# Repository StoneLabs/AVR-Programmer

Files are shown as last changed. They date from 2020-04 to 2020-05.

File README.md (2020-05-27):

  

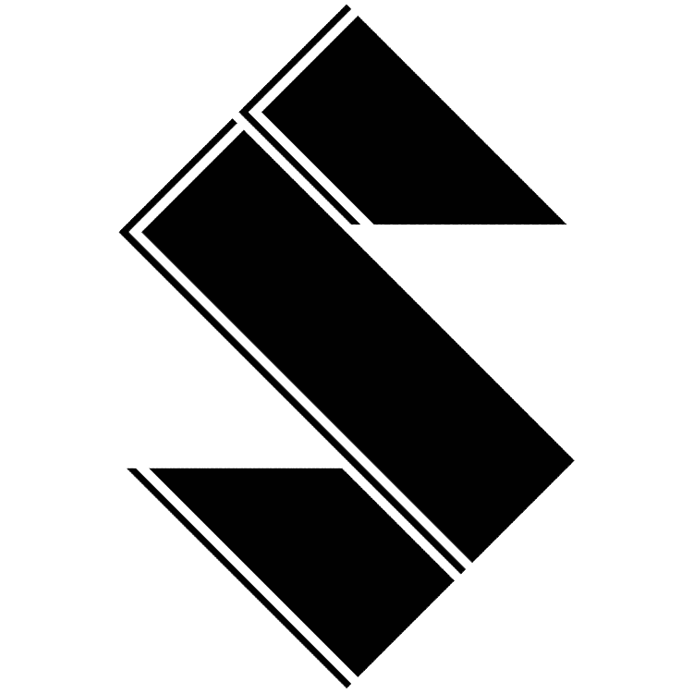
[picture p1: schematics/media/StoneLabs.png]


# Stone Labs. AVR-Programmer
Schematics and firmware for a portable In-Service-Programmer. It is designed to be powered by a 9V battery and uses an OLED Display module for user interaction. INTEL HEX Files can be flashed to target chips via an ISP-6 port directly from an SD-Card.

# PCB

The Programmer is designed to sit on a portable ~9x11cm PCB. Eagle files for the PCB can be found in the `schematics` folder. Target chips can be programmed with the 6-pin Header located at the top of the PCB. There is also an 8Mhz clock pin available (TCLK) in case the target needs an external clock and none is available. BOM for the programmer can be found in `schematics/bom-grouped.csv`. All parts are available from DIGI-KEY. The price per assembled PCB should be around 10-30 bucks depending on the order quantity.

Aside from the programmer, there is target PCB design under `schematics-target`. The target can hold an ATmega328P like chip that can be programmed by connecting the target boards ISP Header to the programmer ISP-Port.

[Picture of PCB revision 1 (Release_V-1.0)](/pcb_v-1.0.png)

| PCB | Version | Status |
| - | - | - |
| Main PCB | Hardware_V-1.0 | Pull-Ups R1, R2 are connected incorrectly (to GND instead of +5V)! Assembled and tested. Works without R1, R2. |
| Main PCB | Hardware_V-1.1 | Fixed only R1, R2 and should work better than V-1.0. Untested! |
| Main PCB | Hardware_V-1.1+ | No functional hardware change. |
| Target PCB | Hardware_V-1.2 | Assembled and tested. Fully functional. |

# INTEL HEX

All `.hex` or `.HEX` files in the root folder of the SD-Card can be flashed to the target using the Programmer. The algorithm used for flashing the program to the target is very robust against weirdly formed hex files (e.g. line swaps, different lengths of lines in the same file, etc.). HEX record types 00, 01, and 02 are fully supported. Type 03 entries will be ignored with a warning sent to the programmers Serial output. Type 04 and 05 are not supported and HEX files containing those record types can't be flashed. (This shouldn't be an issue for AVR chips).

The programmer will also scan all possible bootloader positions for the current target and automatically set the fuse containing the bootloader position bits as needed.

# Supported chips

#32CD32 Supported and tested  
#FFA500 Supported not tested  
#f03c15 Not yet supported  

||Chip||Chip|
| - | - | - | - |
|  #FFA500 | ATmega1280 |  #f03c15 | ATmega329A |
|  #FFA500 | ATmega1281 |  #f03c15 | ATmega329PA |
|  #FFA500 | ATmega1284P |  #f03c15 | ATmega329P |
|  #FFA500 | ATmega1284 |  #f03c15 | ATmega329 |
|  #f03c15 | ATmega128A |  #f03c15 | ATmega32A |
|  #f03c15 | ATmega128RFA1 |  #f03c15 | ATmega32C1 |
|  #f03c15 | ATmega128 |  #f03c15 | ATmega32HVB |
|  #f03c15 | ATmega162 |  #f03c15 | ATmega32M1 |
|  #f03c15 | ATmega164A |  #FFA500 | ATmega32U2 |
|  #f03c15 | ATmega164PA |  #FFA500 | ATmega32U4 |
|  #FFA500 | ATmega164P |  #f03c15 | ATmega32 |
|  #f03c15 | ATmega165A |  #f03c15 | ATmega48A |
|  #f03c15 | ATmega165PA |  #FFA500 | ATmega48PA |
|  #f03c15 | ATmega165P |  #f03c15 | ATmega48P |
|  #f03c15 | ATmega168A |  #f03c15 | ATmega48 |
|  #FFA500 | ATmega168PA |  #f03c15 | ATmega640 |
|  #f03c15 | ATmega168P |  #f03c15 | ATmega644A |
|  #FFA500 | ATmega168V |  #f03c15 | ATmega644PA |
|  #f03c15 | ATmega168 |  #FFA500 | ATmega644P |
|  #f03c15 | ATmega169A |  #f03c15 | ATmega644 |
|  #f03c15 | ATmega169PA |  #f03c15 | ATmega6450A |
|  #f03c15 | ATmega169P |  #f03c15 | ATmega6450P |
|  #f03c15 | ATmega16A |  #f03c15 | ATmega6450 |
|  #f03c15 | ATmega16HVB |  #f03c15 | ATmega645A |
|  #f03c15 | ATmega16M1 |  #f03c15 | ATmega645P |
|  #FFA500 | ATmega16U2 |  #f03c15 | ATmega645 |
|  #FFA500 | ATmega16U4 |  #f03c15 | ATmega6490A |
|  #f03c15 | ATmega16 |  #f03c15 | ATmega6490P |
|  #FFA500 | ATmega2560 |  #f03c15 | ATmega6490 |
|  #FFA500 | ATmega2561 |  #f03c15 | ATmega649A |
|  #f03c15 | ATmega324A |  #f03c15 | ATmega649P |
|  #f03c15 | ATmega324PA |  #f03c15 | ATmega649 |
|  #FFA500 | ATmega324P |  #f03c15 | ATmega64A |
|  #f03c15 | ATmega3250A |  #f03c15 | ATmega64C1 |
|  #f03c15 | ATmega3250PA  |  #f03c15 | ATmega64M1 |
|  #f03c15 | ATmega3250P |  #f03c15 | ATmega64 |
|  #f03c15 | ATmega3250 |  #f03c15 | ATmega8515 |
|  #f03c15 | ATmega325A |  #f03c15 | ATmega8535 |
|  #f03c15 | ATmega325PA |  #f03c15 | ATmega88A |
|  #f03c15 | ATmega325P |  #FFA500 | ATmega88PA |
|  #f03c15 | ATmega325 |  #f03c15 | ATmega88P |
|  #32CD32 | ATmega328P |  #f03c15 | ATmega88 |
|  #FFA500 | ATmega328PB |  #f03c15 | ATmega8A |
|  #FFA500 | ATmega328 |  #FFA500 | ATmega8U2 |
|  #f03c15 | ATmega3290A |  #f03c15 | ATmega8 |
|  #f03c15 | ATmega3290PA  |  #FFA500 | At90USB82 |
|  #f03c15 | ATmega3290P |  #FFA500 | At90USB162 |
|  #f03c15 | ATmega3290 | | |
| | | | |
|  #FFA500 | ATtiny24 |  #FFA500 | ATtiny25 |
|  #FFA500 | ATtiny44 |  #FFA500 | ATtiny45 |
|  #FFA500 | ATtiny84 |  #FFA500 | ATtiny85 |

# License

This is free and unencumbered software released into the public domain.

Anyone is free to copy, modify, publish, use, compile, sell, or
distribute this software, either in source code form or as a compiled
binary, for any purpose, commercial or non-commercial, and by any
means.

In jurisdictions that recognize copyright laws, the author or authors
of this software dedicate any and all copyright interest in the
software to the public domain. We make this dedication for the benefit
of the public at large and to the detriment of our heirs and
successors. We intend this dedication to be an overt act of
relinquishment in perpetuity of all present and future rights to this
software under copyright law.

THE SOFTWARE IS PROVIDED "AS IS", WITHOUT WARRANTY OF ANY KIND,
EXPRESS OR IMPLIED, INCLUDING BUT NOT LIMITED TO THE WARRANTIES OF
MERCHANTABILITY, FITNESS FOR A PARTICULAR PURPOSE AND NONINFRINGEMENT.
IN NO EVENT SHALL THE AUTHORS BE LIABLE FOR ANY CLAIM, DAMAGES OR
OTHER LIABILITY, WHETHER IN AN ACTION OF CONTRACT, TORT OR OTHERWISE,
ARISING FROM, OUT OF OR IN CONNECTION WITH THE SOFTWARE OR THE USE OR
OTHER DEALINGS IN THE SOFTWARE.

For more information, please refer to <http://unlicense.org/>

### That being said, I'd really like to hear from you if you plan on using this project somewhere. And I for sure wouldn't mind some part if you use it commercially ;) (e.g. selling it etc.)

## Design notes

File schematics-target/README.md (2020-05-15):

# Schematics

Eagle files for a simple target board holding an ATmega328P like chip in PDIP packaging. It can be used to easily hook up target chips.

The Graphics on the pcb can be found in media/.

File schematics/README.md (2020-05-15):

# Schematics

Eagle files for the programmer board as well as a diagram for arduino based testing (arduino_wiring.sch).

Parts.lbr contains the OLED screen used. (see also oled.jpg)

The Graphics on the pcb can be found in media/.

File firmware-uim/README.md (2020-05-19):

# UIM: User Interface Module

This is the firmware for the lower (on the pcb) chip handling the OLED screen and user input.

Actions are send to the programmer chip via I2C.

# Flowchart of user interaction

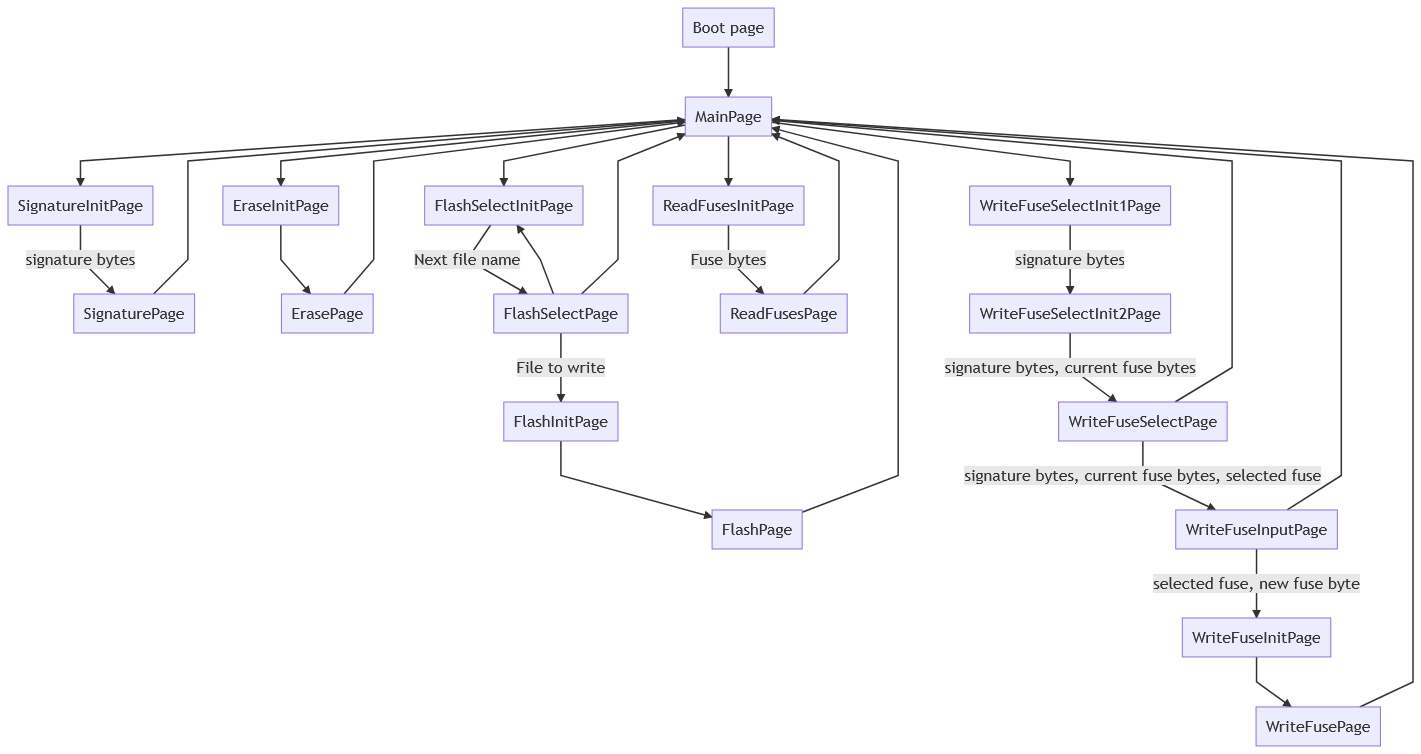
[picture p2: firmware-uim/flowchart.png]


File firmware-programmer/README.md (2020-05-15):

# Programmer

This is the firmware for the upper (on the pcb) chip handling the SPI programming of the target.

Actions are received by the UIM chip via I2C.

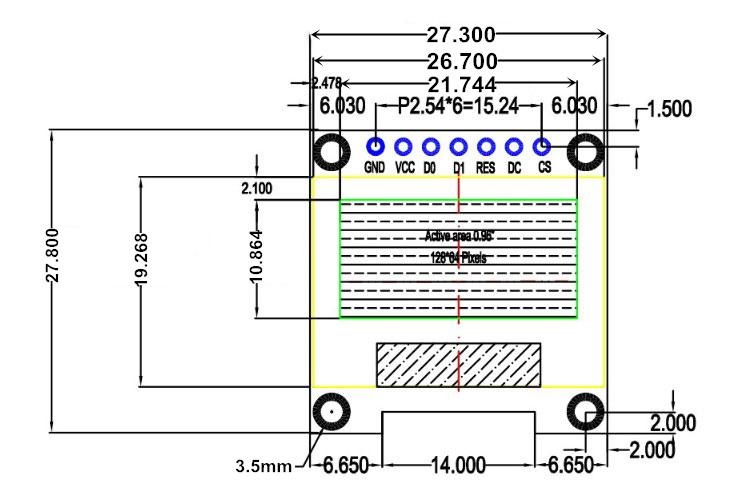
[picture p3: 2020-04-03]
schematics/oled.jpg

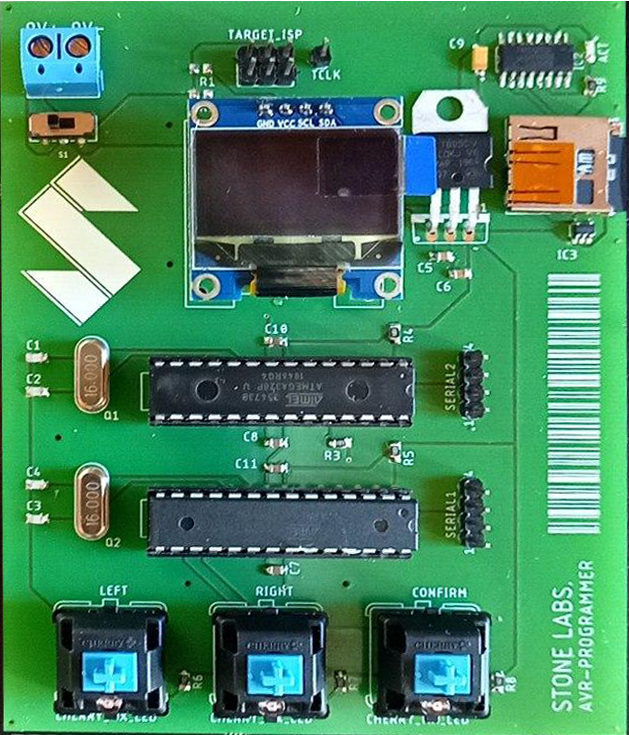
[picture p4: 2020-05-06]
pcb_v-1.0.png

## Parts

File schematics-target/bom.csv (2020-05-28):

Part | Value | Device | Package | Description
C1 | 22pF | C-EUC0805 | C0805 | CAPACITOR, European symbol
C2 | 22pF | C-EUC0805 | C0805 | CAPACITOR, European symbol
C3 | 100nF | C-EUC0805 | C0805 | CAPACITOR, European symbol
C4 | 100nF | C-EUC0805 | C0805 | CAPACITOR, European symbol
ISP | AVR-ISP-6 | AVR-ISP-6 | AVR-ISP-6 | AVR ISP-6 Serial Programming Header
Q1 | 16Mhz | XTAL/S | QS | CRYSTAL
R1 | 10k | R-EU_R0805 | R0805 | RESISTOR, European symbol
TARGET_ATMEGA328P | ATMEGA48/88/168-PU | ATMEGA48/88/168-PU | DIL28-3

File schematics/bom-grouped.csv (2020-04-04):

count Device | Device | Package | Value | Status | Digikey
5 | C-EUC0805 | C0805 | 100nF | ORDERED | ‎C0805C104Z5VACTU‎
5 | R-EU_R0805 | R0805 | 10k | ORDERED | RC0805JR-0710KL‎
4 | C-EUC0805 | C0805 | 22pF | ORDERED | ‎C0805C220J5GACTU‎
3 | CHERRY_MX_LED | CHERRY_MX_LED | CHERRY_MX_LED | ORDERED | MX1A-E1NN‎
3 | R-EU_R0805 | R0805 | 1k | ORDERED | RC0805JR-071KL‎
2 | ATMEGA48/88/168-PU | DIL28-3 | ATMEGA48/88/168-PU | Stock | Stock
2 | MA04-1 | MA04-1 |  | Stock | Stock
2 | XTAL/S | QS | 16Mhz | Stock | Stock
1 | 128X64-I2C-OLED | 128X64-I2C-OLED | 128X64-I2C-OLED | Stock | Stock
1 | 4050D | SO16 | 4050D | ORDERED | 74HC4050D,653‎
1 | 452404020202 | 452404020202 |  | ORDERED | 45 2404020202
1 | 7805TV | TO220V | 7805TV | Stock | Stock
1 | AVR-ISP-6 | AVR-ISP-6 | AVR-ISP-6 | Stock | Stock
1 | C-EUC0805 | C0805 | 330nF | ORDERED | ‎885012207019‎
1 | CPOL-USA/3216-18R | A/3216-18R | 10uF | ORDERED | TAJA106K006SNJ‎
1 | LEDCHIP-LED0805 | CHIP-LED0805 | RED | ORDERED | LTST-S220KGKT‎
1 | LP298XS | SOT23-5L | LP298XS | ORDERED | LP2980AIM5-3.0/NOPB‎
1 | MICROSD | MICROSD | MICROSD | ORDERED | 693071010811‎
1 | PINHD-1X1 | 1X01 |  | Stock | Stock
1 | R-US_R0805 | R0805 | 1K | ORDERED | RC0805JR-071KL‎
1 | W237-102 | W237-102 | 9V | Stock | Stock
0

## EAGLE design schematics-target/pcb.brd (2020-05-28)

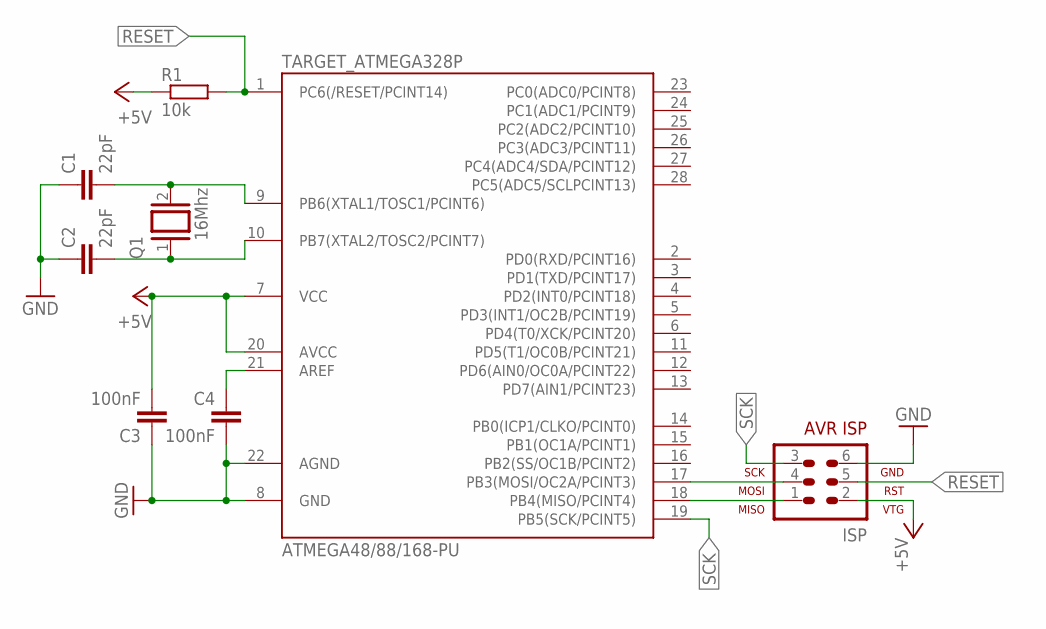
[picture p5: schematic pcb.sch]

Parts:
C1, C2: 22pF; C0805
C3, C4: 100nF; C0805
ISP: AVR-ISP-6
Q1: 16Mhz; QS
R1: 10k; R0805
TARGET_ATMEGA328P: ATMEGA48/88/168-PU; DIL28-3

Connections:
+5V: C3.2, ISP.2, R1.1, TARGET_ATMEGA328P.7 (VCC), TARGET_ATMEGA328P.20 (AVCC)
GND: C1.1, C2.1, C3.1, C4.2, ISP.6, TARGET_ATMEGA328P.8 (GND), TARGET_ATMEGA328P.22 (AGND)
unnamed: ISP.4, TARGET_ATMEGA328P.17 (PB3(MOSI/OC2A/PCINT3))
unnamed: ISP.1, TARGET_ATMEGA328P.18 (PB4(MISO/PCINT4))
unnamed: C1.2, Q1.2, TARGET_ATMEGA328P.9 (PB6(XTAL1/TOSC1/PCINT6))
unnamed: C2.2, Q1.1, TARGET_ATMEGA328P.10 (PB7(XTAL2/TOSC2/PCINT7))
unnamed: C4.1, TARGET_ATMEGA328P.21 (AREF)
RESET: ISP.5, R1.2, TARGET_ATMEGA328P.1 (PC6(/RESET/PCINT14))
SCK: ISP.3, TARGET_ATMEGA328P.19 (PB5(SCK/PCINT5))

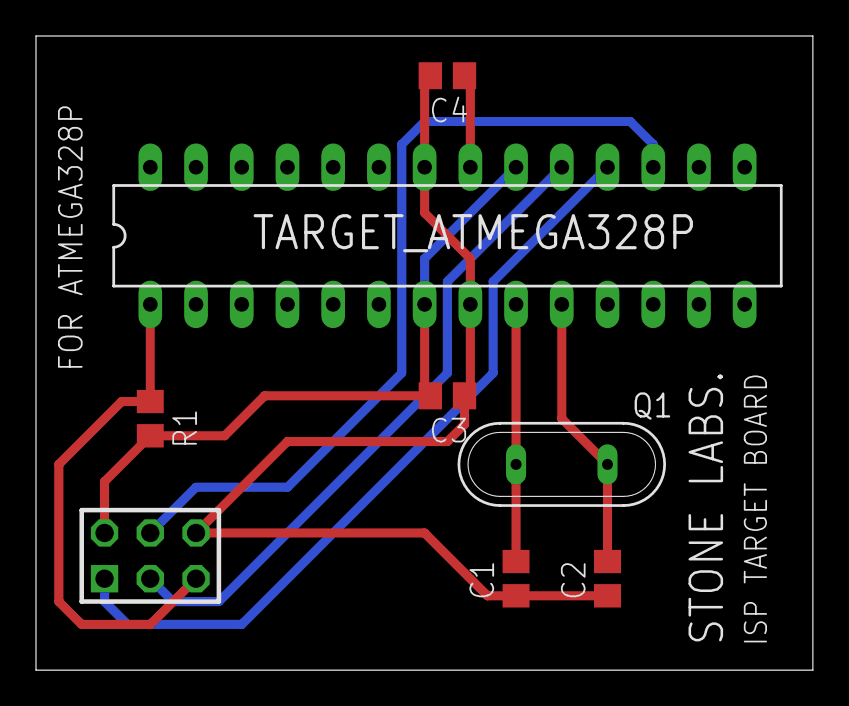
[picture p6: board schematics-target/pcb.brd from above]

Board: 2 copper layers, 43.2 x 35.2 mm, 8 parts (0 on the bottom side), 9 nets.

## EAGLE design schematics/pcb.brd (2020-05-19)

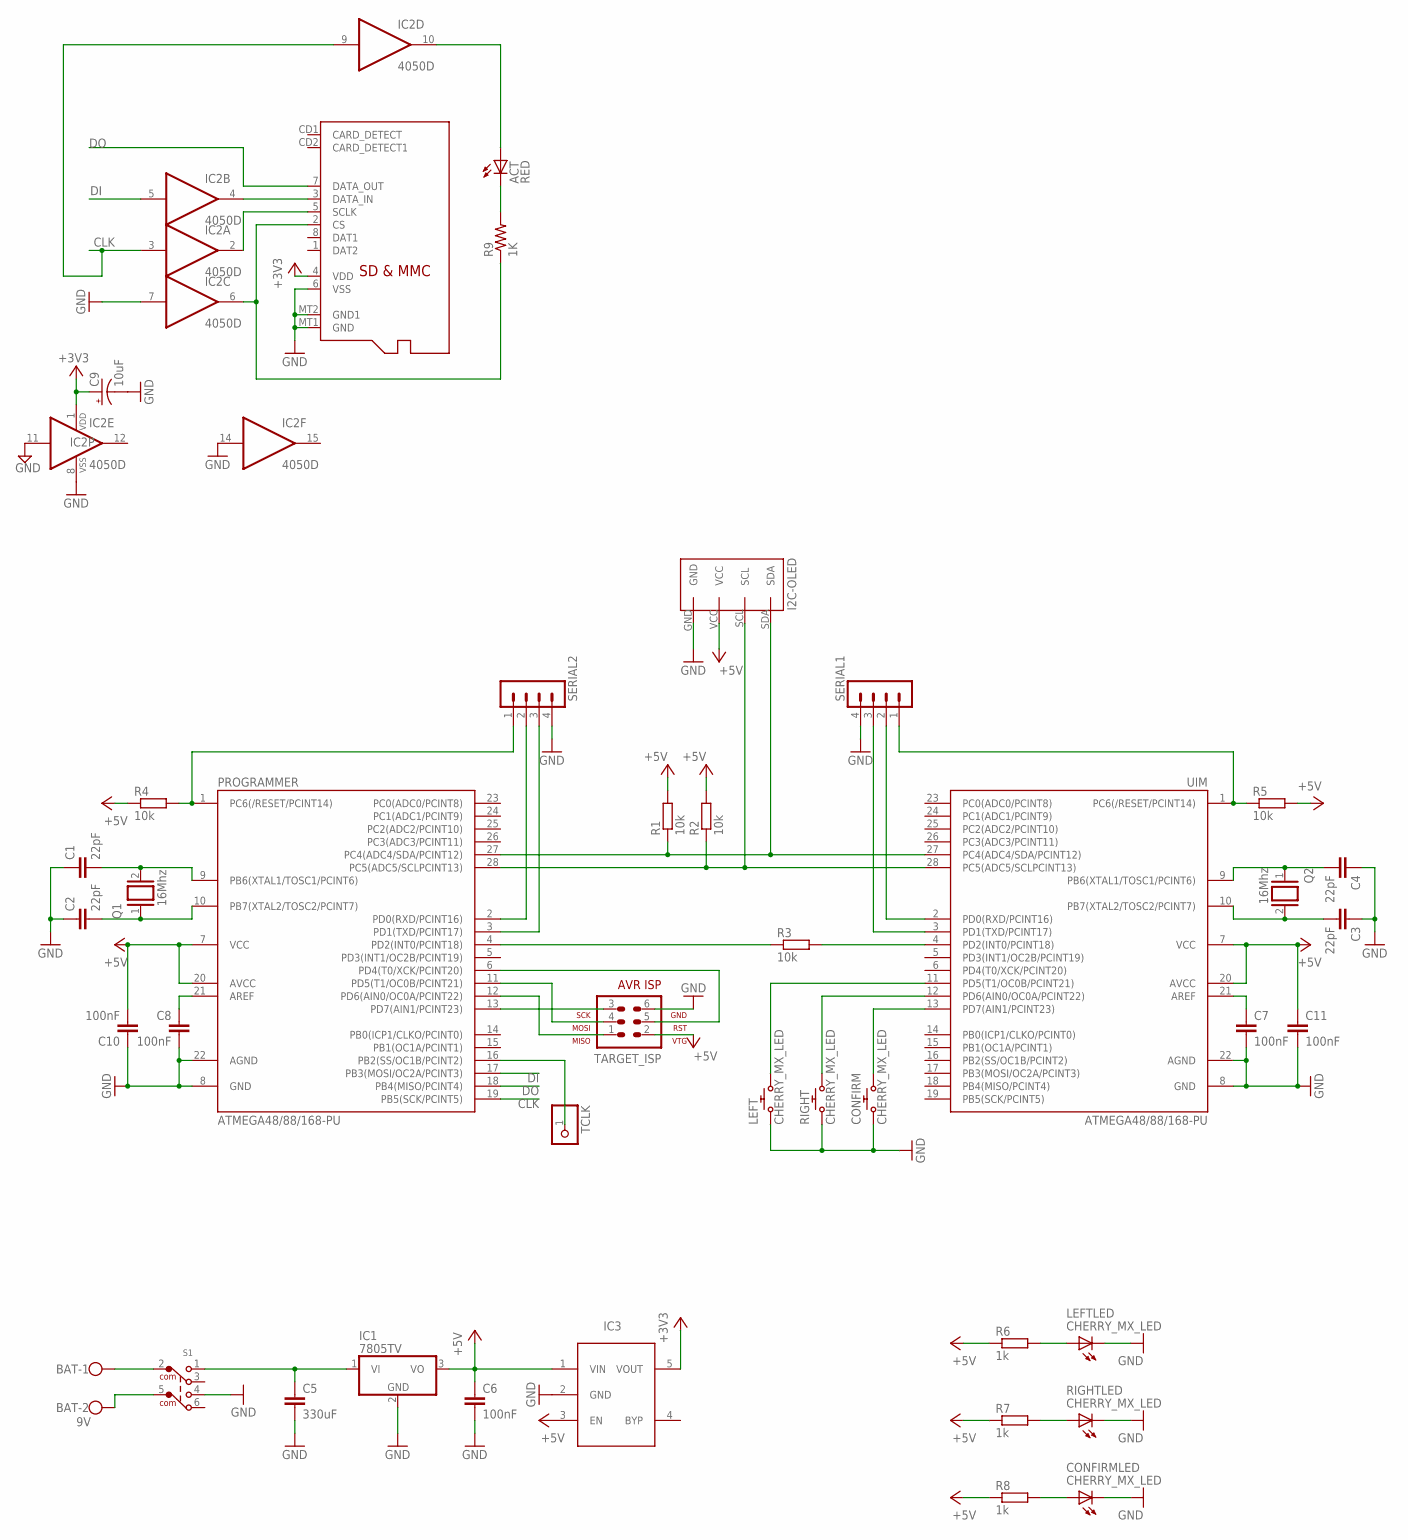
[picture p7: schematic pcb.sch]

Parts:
ACT: RED; CHIP-LED0805
BAT: 9V; W237-102
C1, C2, C3, C4: 22pF; C0805
C5: 330uF; C0805
C6, C7, C8, C10, C11: 100nF; C0805
C9: 10uF; A/3216-18R
CONFIRM: CHERRY_MX_LED
IC1: 7805TV; TO220V
IC2: 4050D; SO16
IC3: LP298XS; SOT23-5L
LEFT: CHERRY_MX_LED
PROGRAMMER: ATMEGA48/88/168-PU; DIL28-3
Q1, Q2: 16Mhz; QS
R1, R2, R3, R4, R5: 10k; R0805
R6, R7, R8: 1k; R0805
R9: 1K; R0805
RIGHT: CHERRY_MX_LED
S1: 452404020202
SERIAL1, SERIAL2: MA04-1
TARGET_ISP: AVR-ISP-6
TCLK: PINHD-1X1; 1X01
U$1: 128X64-I2C-OLED
UIM: ATMEGA48/88/168-PU; DIL28-3
X1: MICROSD

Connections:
9V+: C5.1, IC1.1 (VI), S1.1
+3V3: C9.+, IC2.1 (VDD), IC3.5 (VOUT), X1.4 (VDD)
+5V: C6.1, C10.2, C11.1, IC1.3 (VO), IC3.1 (VIN), IC3.3 (EN), PROGRAMMER.7 (VCC), PROGRAMMER.20 (AVCC), R1.2, R2.2, R4.1, R5.2, R6.1, R7.1, R8.1, TARGET_ISP.2, U$1.VCC, UIM.7 (VCC), UIM.20 (AVCC)
B$1: PROGRAMMER.11 (PD5(T1/OC0B/PCINT21)), TARGET_ISP.4
BAT+: BAT.1, S1.2 (COM)
BAT-: BAT.2, S1.5 (COM1)
CLK: IC2.3 (I), IC2.9 (I), PROGRAMMER.19 (PB5(SCK/PCINT5))
DI: IC2.5 (I), PROGRAMMER.17 (PB3(MOSI/OC2A/PCINT3))
DO: PROGRAMMER.18 (PB4(MISO/PCINT4)), X1.7 (DATA_OUT)
GND: C1.1, C2.1, C3.1, C4.1, C5.2, C6.2, C7.2, C8.2, C9.-, C10.1, C11.2, CONFIRM.L2 (C), CONFIRM.S1 (1), IC1.2 (GND), IC2.7 (I), IC2.8 (VSS), IC2.11 (I), IC2.14 (I), IC3.2 (GND), LEFT.L2 (C), LEFT.S1 (1), PROGRAMMER.8 (GND), PROGRAMMER.22 (AGND), RIGHT.L2 (C), RIGHT.S1 (1), S1.4, SERIAL1.4, SERIAL2.4, TARGET_ISP.6, U$1.GND, UIM.8 (GND), UIM.22 (AGND), X1.6 (VSS), X1.MT1 (GND), X1.MT2 (GND1)
unnamed: PROGRAMMER.28 (PC5(ADC5/SCLPCINT13)), R2.1, U$1.SCL, UIM.28 (PC5(ADC5/SCLPCINT13))
unnamed: PROGRAMMER.27 (PC4(ADC4/SDA/PCINT12)), R1.1, U$1.SDA, UIM.27 (PC4(ADC4/SDA/PCINT12))
unnamed: PROGRAMMER.4 (PD2(INT0/PCINT18)), R3.1
unnamed: R3.2, UIM.4 (PD2(INT0/PCINT18))
unnamed: PROGRAMMER.1 (PC6(/RESET/PCINT14)), R4.2, SERIAL2.1
unnamed: R5.1, SERIAL1.1, UIM.1 (PC6(/RESET/PCINT14))
unnamed: C1.2, PROGRAMMER.9 (PB6(XTAL1/TOSC1/PCINT6)), Q1.2
unnamed: C2.2, PROGRAMMER.10 (PB7(XTAL2/TOSC2/PCINT7)), Q1.1
unnamed: LEFT.S2 (2), UIM.11 (PD5(T1/OC0B/PCINT21))
unnamed: C3.2, Q2.2, UIM.10 (PB7(XTAL2/TOSC2/PCINT7))
unnamed: C4.2, Q2.1, UIM.9 (PB6(XTAL1/TOSC1/PCINT6))
unnamed: PROGRAMMER.12 (PD6(AIN0/OC0A/PCINT22)), TARGET_ISP.1
unnamed: PROGRAMMER.13 (PD7(AIN1/PCINT23)), TARGET_ISP.3
unnamed: PROGRAMMER.6 (PD4(T0/XCK/PCINT20)), TARGET_ISP.5
unnamed: RIGHT.S2 (2), UIM.12 (PD6(AIN0/OC0A/PCINT22))
unnamed: CONFIRM.S2 (2), UIM.13 (PD7(AIN1/PCINT23))
unnamed: LEFT.L1 (A), R6.2
unnamed: R7.2, RIGHT.L1 (A)
unnamed: CONFIRM.L1 (A), R8.2
unnamed: C7.1, UIM.21 (AREF)
unnamed: C8.1, PROGRAMMER.21 (AREF)
unnamed: ACT.A, IC2.10 (O)
unnamed: IC2.2 (O), X1.5 (SCLK)
unnamed: IC2.6 (O), R9.1, X1.2 (CS)
unnamed: ACT.C, R9.2
unnamed: IC2.4 (O), X1.3 (DATA_IN)
unnamed: PROGRAMMER.16 (PB2(SS/OC1B/PCINT2)), TCLK.1
unnamed: PROGRAMMER.2 (PD0(RXD/PCINT16)), SERIAL2.2
unnamed: PROGRAMMER.3 (PD1(TXD/PCINT17)), SERIAL2.3
unnamed: SERIAL1.2, UIM.2 (PD0(RXD/PCINT16))
unnamed: SERIAL1.3, UIM.3 (PD1(TXD/PCINT17))

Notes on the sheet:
I2C-OLED

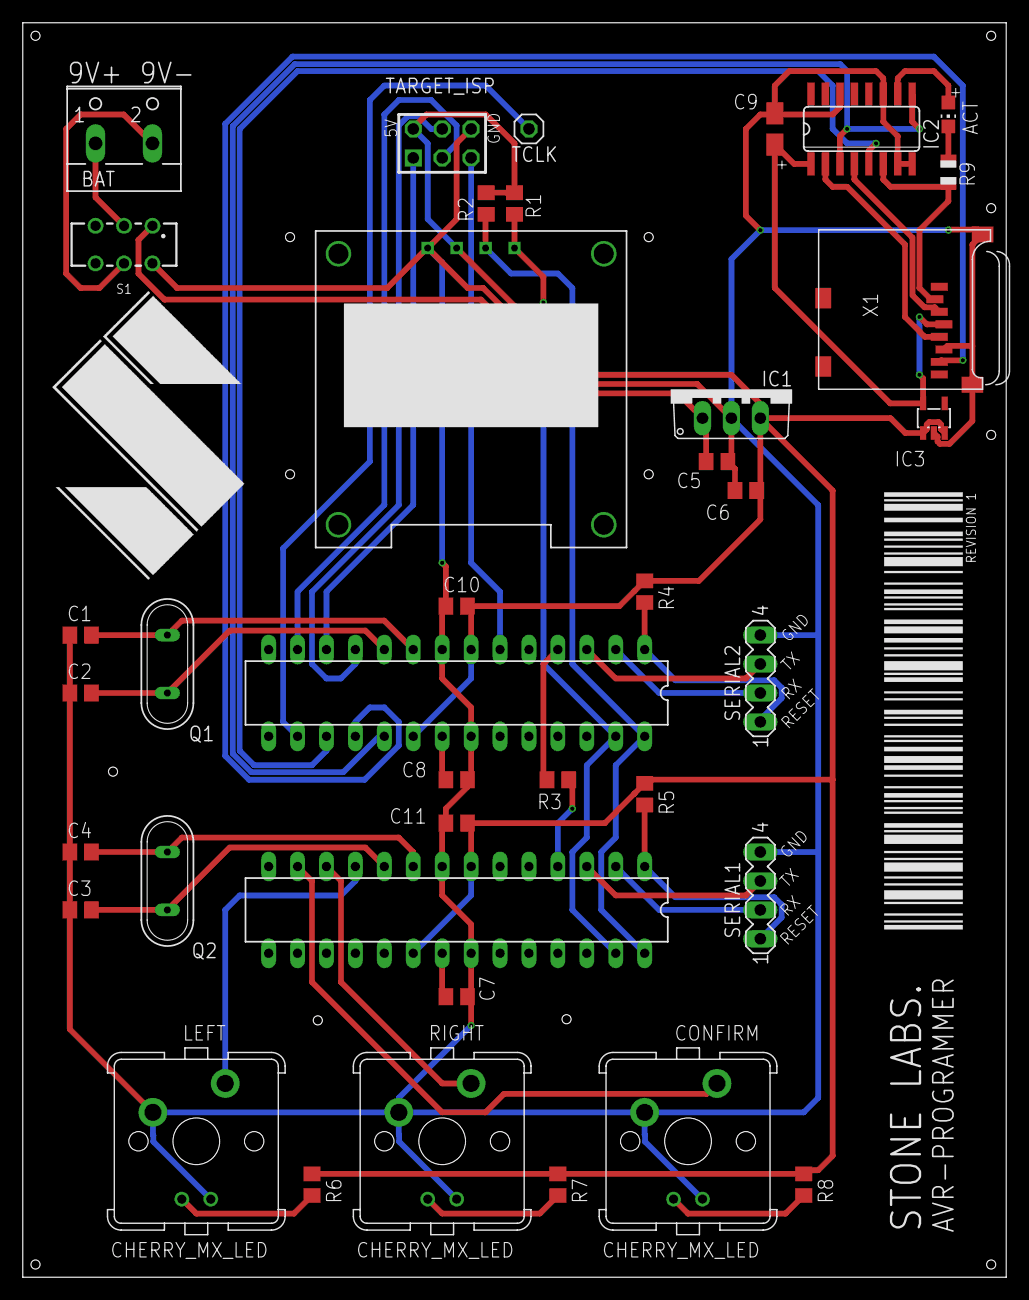
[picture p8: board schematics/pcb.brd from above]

Board: 2 copper layers, 86.4 x 110.2 mm, 39 parts (0 on the bottom side), 41 nets.

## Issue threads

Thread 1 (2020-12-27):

Readme colors only color codes

p3h3, 2020-12-27:
Main readme under the supported and tested section is displayed as:
#32CD32 Supported and tested
#FFA500 Supported not tested
instead of the actual colors yellow/orange and green.

StoneLabs, 2020-12-28:
Huh, it seems that the certificate for via.placeholder.com expired on 12/26/2020.
I'll wait a couple of days to see if it gets fixed. If not I will put the images inside the repository.

StoneLabs, 2020-12-30:
Fixed.

Closed 2020-12-30.

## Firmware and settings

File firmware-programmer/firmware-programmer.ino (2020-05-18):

#define XSTR(s) STR(s)
#define STR(s) #s

#define __PVERSION__ "v-1.2"

// External Dependencies
#include <SPI.h>
#include <SdFat.h>
#include <Wire.h>

// Debug level can be changed in debug.h
#include "src/debug.h"
#include "src/programmer/bbprogrammer.h"
#include "i2c_enums.h"
#include "helper.h"

#define P_SCK 7
#define P_MISO 6
#define P_MOSI 5
#define P_RESET 4

using namespace programmer;

#define SFN_LENGTH 13

typedef struct {
    byte cmd;
    byte data[31];
} Command;
typedef struct {
    bool busy;
    byte cmd;
    byte data[29];
    byte error;
} Answer;


// Global variables
Command command;
Answer answer;
SdFat sd;
SdFile file;

BBProgrammer* bbprogrammer = nullptr;

void setup() {
    Serial.begin(115200);
    while (!Serial) {}

    Debugln(DEBUG_INFO, F("\n\nStone Labs. Smart ISP"));
    Debugln(DEBUG_INFO, F("SmartISP - Programmer Module"));
    Debugln(DEBUG_INFO, F("Verion " XSTR(__PVERSION__) " compiled at " __DATE__ " " __TIME__ " using Arduino IDE version " XSTR(ARDUINO)  " Debug level " XSTR(DEBUG)));

    Debugln(DEBUG_INFO, F("\n-> Starting I2C slave mode."));
    Wire.begin(0x08);                // join i2c bus with address #8
    Wire.onRequest(requestEvent);
    Wire.onReceive(receiveEvent);

    Debugln(DEBUG_INFO, F("\n-> Starting 8 Mhz Clock on Pin 9."));

    // set up 8 MHz timer on PIN 10 (OC1B)
    // https://arduino.stackexchange.com/questions/16698/arduino-constant-clock-output
    pinMode(10, OUTPUT);
    // set up Timer 1
    TCCR1A = bit(COM1B0);  // toggle OC1B on Compare Match
    TCCR1B = bit(WGM12) | bit(CS10);   // CTC, no prescaling
    OCR1B = 0;       // output every cycle

    Debug(DEBUG_INFO, F("\n-> Initializing SD card..."));
    sd.begin(3, SPI_HALF_SPEED); // We dont need an SD card to start
    //if (!sd.begin(3, SPI_HALF_SPEED))
    //    sd.initErrorHalt();

    Debugln(DEBUG_INFO, F(" [OK]"));

    // List all files in root directory.
    // The volume working directory, vwd, is root.
#if DEBUG >= DEBUG_INFO
    while (file.openNext(sd.vwd(), O_READ))
    {
        Debug(DEBUG_INFO, F("|-- "));
        file.printName(&Serial);
        Debug(DEBUG_INFO, F(" "));
        file.printModifyDateTime(&Serial);
        Debugln(DEBUG_INFO, F(""));
        file.close();
    }
    sd.vwd()->rewind();
#endif
    
    Debugln(DEBUG_INFO, F("\n-> Initializing Programmer."));
    bbprogrammer = new BBProgrammer(P_SCK, P_MOSI, P_MISO, P_RESET);

    Debugln(DEBUG_INFO, F("\n-> Now accepting commands."));
    answer.busy = false;
    pinMode(2, OUTPUT);
}

void answerError(byte error)
{
    answer.error = error;
    answer.busy = false;
    Debug(DEBUG_INFO, F("-> Command failed with error: "));
    Debugln(DEBUG_INFO, error, HEX);
}

void loop()
{
    if (answer.busy)
    {
        Serial.print("\n==> Received command: ");
        Serial.println(answer.cmd, HEX);

        // PING command returns cmd_ping
        switch (answer.cmd)
        {
        case cmd_ping:
            {
                Debugln(DEBUG_INFO, F("-> Responsing to ping."));
                answer.data[0] = cmd_ping;
            }
            break;
        case cmd_readSignature:
            {
                // Read signature bytes
                Debugln(DEBUG_INFO, F("-> Entering Programming mode."));
                if (!bbprogrammer->startProgramming(5))
                {
                    answerError(error_programmingMode);
                    return;
                }
                Debugln(DEBUG_INFO, F("-> Reading signature byte."));
                bbprogrammer->readSignatureBytes(answer.data[0], answer.data[1], answer.data[2]);
                Debugln(DEBUG_INFO, F("-> Ending Programming mode."));
                bbprogrammer->stopProgramming();
            }
            break;
        case cmd_erase:
            {
                // Erase Chip signature
                Debugln(DEBUG_INFO, F("-> Entering Programming mode."));
                if (!bbprogrammer->startProgramming(5))
                {
                    answerError(error_programmingMode);
                    return;
                }
                Debugln(DEBUG_INFO, F("-> Erasing chip."));
                bbprogrammer->erase();
                Debugln(DEBUG_INFO, F("-> Ending Programming mode."));
                bbprogrammer->stopProgramming();
            }
            break;
        case cmd_readFuses:
            {
                // Read fuse bytes
                Debugln(DEBUG_INFO, F("-> Entering Programming mode."));
                if (!bbprogrammer->startProgramming(5))
                {
                    answerError(error_programmingMode);
                    return;
                }

                Debugln(DEBUG_INFO, F("-> Reading Fuses."));
                bbprogrammer->readFuses();
                printFuses(bbprogrammer->getFuses());

                // Answer with fuse bytes
                answer.data[lowFuse] = bbprogrammer->getFuses().low;
                answer.data[highFuse] = bbprogrammer->getFuses().high;
                answer.data[extFuse] = bbprogrammer->getFuses().extended;
                answer.data[lockFuse] = bbprogrammer->getFuses().lock;
                answer.data[calibrationFuse] = bbprogrammer->getFuses().calibration;

                Debugln(DEBUG_INFO, F("-> Ending Programming mode."));
                bbprogrammer->stopProgramming();
            }
            break;
        case cmd_openNextFile:
            { // Explicit block for case variable foundFile and file_sfn
                Debugln(DEBUG_INFO, F("-> Opening next file"));

                bool foundFile = false;
                while (file.openNext(sd.vwd(), O_READ))
                {
                    foundFile = true;

                    Debugln(DEBUG_INFO, F("Opened file."));
                    Debug(DEBUG_INFO, F("Name: "));
#if DEBUG >= DEBUG_INFO
                    file.printName(&Serial);
#endif
                    Debug(DEBUG_INFO, F(" SFN: "));
#if DEBUG >= DEBUG_INFO
                    file.printSFN(&Serial);
#endif

                    // Copy SFN in tmp buffer
                    char file_sfn[SFN_LENGTH];
                    file.getSFN(file_sfn); // 13. char is 0x00

                    // Get length and compare last 4 bytes with .HEX or .hex
                    byte file_sfn_length = strlen(file_sfn);
                    if (file_sfn_length > 4 &&
                        (strcmp(file_sfn + file_sfn_length - 4, ".hex") == 0 ||
                            strcmp(file_sfn + file_sfn_length - 4, ".HEX") == 0))
                    {
                        // Files is .hex => copy tmp buffer to answer buffer
                        Debugln(DEBUG_INFO, F(" [OK: .HEX]"));
                        memcpy(answer.data, file_sfn, SFN_LENGTH);

                        file.close();
                        break;
                    }
                    else
                    {
                        // Files is not .hex => open next file via while
                        Debugln(DEBUG_INFO, F(" [IGNORE]"));
                        file.close();
                        continue;
                    }
                }
                if (!foundFile)
                {
                    // Not a single file was found
                    //  Rewind working directory and return
                    //  empty buffer.
                    sd.vwd()->rewind();
                    Debugln(DEBUG_INFO, F("No file found. Rewinding."));
                }
            }
            break;
        case cmd_flashFile:
            {
                Debug(DEBUG_INFO, F("\n-> Flashing HEX source /"));
                Debugln(DEBUG_INFO, (char*)command.data);
                if (!file.open((char*)command.data, O_READ))
                {
                    answerError(error_openFile);
                    return;
                }

                // Flash file. Will not be closed by flashFile()
                byte status = flashFile(&file, bbprogrammer);
                file.close();

                if (status > 0x00)
                {
                    answerError(status);
                    return;
                }
            }
            break;
        case cmd_writeLowFuse:
            [[fallthrough]];
        case cmd_writeHighFuse:
            [[fallthrough]];
        case cmd_writeExtFuse:
            [[fallthrough]];
        case cmd_writeLockFuse:
            {
                if (command.data[0] != command.data[1])
                {
                    answerError(error_fuseCheckMismatch);
                    return;
                }
                // Read signature bytes
                Debugln(DEBUG_INFO, F("-> Entering Programming mode."));
                if (!bbprogrammer->startProgramming(5))
                {
                    answerError(error_programmingMode);
                    return;
                }
                if (!bbprogrammer->readSignature())
                {
                    answerError(error_fuseWithoutSignature);
                    return;
                }
                switch (command.cmd)
                {
                case cmd_writeLowFuse:
                    Debug(DEBUG_INFO, F("-> Writing low fuse to:"));
                    Debugln(DEBUG_INFO, command.data[0], BIN);
                    bbprogrammer->setLowFuse(command.data[0]);
                    break;
                case cmd_writeHighFuse:
                    Debug(DEBUG_INFO, F("-> Writing high fuse."));
                    Debugln(DEBUG_INFO, command.data[0], BIN);
                    if (!bbprogrammer->setHighFuse(command.data[0]))
                    {
                        bbprogrammer->stopProgramming();
                        answerError(error_refusedByProgrammer);
                        return;
                    }
                    break;
                case cmd_writeExtFuse:
                    Debug(DEBUG_INFO, F("-> Writing ext. fuse."));
                    Debugln(DEBUG_INFO, command.data[0], BIN);
                    bbprogrammer->setExtFuse(command.data[0]);
                    break;
                case cmd_writeLockFuse:
                    Debug(DEBUG_INFO, F("-> Writing lock bits."));
                    Debugln(DEBUG_INFO, command.data[0], BIN);
                    bbprogrammer->setLockBits(command.data[0]);
                    break;
                }
                Debugln(DEBUG_INFO, F("-> Ending Programming mode."));
                bbprogrammer->stopProgramming();
            }
            break;
        default:
            answerError(error_unknownCommand);
            return;
        }

        Debugln(DEBUG_INFO, F("-> Command finished."));
        answer.busy = false;
    }
}

// Interrupt handler
void receiveEvent(int HowMany)
{
    if (HowMany != sizeof(command) || answer.busy == true)
        return;

    // Read incoming bytes to command
    // Clearing command argument buffer is not needed
    // as it will be overwritten anyway.
    byte* p = (byte*)&command;
    for (unsigned int i = 0; i < sizeof command; i++)
        *(p++) = Wire.read();

    // Clear error byte and busy bit
    answer.busy = true;
    answer.error = 0x00;

    // Set response command to incoming command
    answer.cmd = command.cmd;

    // Clear response array
    for (int i = 0; i < 28; i++)
        answer.data[i] = 0x00;
}

void requestEvent()
{
    Wire.write((byte*)&answer, sizeof(answer));
}

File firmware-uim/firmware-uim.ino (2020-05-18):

#define XSTR(s) STR(s)
#define STR(s) #s

#define __PVERSION__ "v-1.2"

#include "src/page.h"
#include "src/pageManager.h"
#include "src/pages/bootPage.h"
#include "I2CHelper.h"

#include <SSD1306AsciiWire.h>
#include <Wire.h>

SSD1306AsciiWire display;
PageManager* ui;

void setup() {
    Serial.begin(115200);
    while (!Serial) {};
    
    // Connect screen
    Serial.println(F("\n\nStone Labs. Smart ISP"));
    Serial.println(F("SmartISP - User Interface Module"));
    Serial.println(F("Verion " XSTR(__PVERSION__) " compiled at " __DATE__ " " __TIME__ " using Arduino IDE version " XSTR(ARDUINO)  " Debug level " XSTR(DEBUG)));

    display.begin(&Adafruit128x64, 0x3C);
    display.setFont(Adafruit5x7);
    
    // Setup input button
    pinMode(5, INPUT_PULLUP);
    pinMode(6, INPUT_PULLUP);
    pinMode(7, INPUT_PULLUP);

    // Pin change interrupt mask for D5,6,7
    PCMSK2 = bit(PCINT21) | bit(PCINT22) | bit(PCINT23);
    PCIFR |= bit(PCIF2);    // clear any outstanding interrupts on Interrupt block 2
    PCICR |= bit(PCIE2);    // enable pin change interrupts on Interrupt block 2 (D0-7)

    // Setup page manager with boot page as start page.
    // Minimum welcome screen duration 3 seconds.
    ui = new PageManager(&display);
    ui->changePage(new BootPage(ui, 3000));
}

bool press5 = false, press6 = false, press7 = false;
void loop()
{
    ui->updatePage();
    if (press5) 
    { 
        ui->left();
        press5 = false; 
    }
    if (press6) 
    {
        ui->right();
        press6 = false; 
    }
    if (press7) 
    {
        ui->confirm();
        press7 = false; 
    }
}

byte vector_old = 0xFF;
ISR(PCINT2_vect)
{
    // Check for bitchange 0->1 on D7
    if (((vector_old ^ PIND) & bit(PIND7)) && !(PIND & bit(PIND7)))
        press7 = true;
    // Check for bitchange 0->1 on D6
    if (((vector_old ^ PIND) & bit(PIND6)) && !(PIND & bit(PIND6)))
        press6 = true;
    // Check for bitchange 0->1 on D5
    if (((vector_old ^ PIND) & bit(PIND5)) && !(PIND & bit(PIND5)))
        press5 = true;

    vector_old = PIND;
}

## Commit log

2020-03-18 Implemented Fuse reading; Fixed clock (now on OC1B)
    [bbprogrammer.cpp]
2020-03-19 Implemented high and low fuse writing; Mulitple minor bugfixes
    [bbprogrammer.cpp]
2020-03-20 Added user interface module project with sample sketch
2020-03-22 Implemented InitPage which check for programmer response instead of fixed time
    [I2CHelper.cpp, I2CHelper.h, firmware-uim.ino]
2020-03-23 Implemented current UIM functionality in firmware_programmer; Minor fixes in BBProgrammer
    [I2CHelper.h, bbprogrammer.cpp, firmware-programmer.ino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]
2020-03-23 Implemented fuse reading page
2020-03-24 Implemented Flashing of file with functionality (currently constant file) in UIM
2020-03-24 Removed main Init Page as it is not really needed; Fixed multiple memory "violation" issues where page members would be used after being deleted; Minor optimizations, changes, fixes
    [firmware-programmer.ino, firmware-uim.ino]
2020-03-24 Fixed programmer debug output on command 0x11
    [firmware-programmer.ino]
2020-03-24 Implemented Programmer error handling functionality in UIM
    [I2CHelper.h]
2020-03-24 Added numerous error checks
    [I2CHelper.h, bbprogrammer.cpp, firmware-programmer.ino]
2020-03-24 Implemented write Fuse selection Page.
2020-03-24 Implemented Fuse writing page without functionality in programmer
2020-03-24 Fixed left button behaviour in tabPages
2020-03-24 Fully implemented fuse changing with full error handling
    [I2CHelper.h, bbprogrammer.cpp, firmware-programmer.ino]
2020-03-24 Fixed bugs in firmware-programmer
    [firmware-programmer.ino]
2020-03-25 Added Arduino based wiring schematics
    [arduino_wiring.sch]
2020-03-26 Fixed mistakes in arduino based schematics
    [arduino_wiring.sch]
2020-03-28 Started work on PCB schematics
    [pcb.sch]
2020-03-28 Further work on pcb schematics
    [pcb.sch]
2020-03-29 Added SD-Card to PCB
    [pcb.sch]
2020-03-29 Added Serial debug and reprogramming port to ICs
    [pcb.sch]
2020-03-29 Added PCB Board with placed components (WIP)
    [pcb.brd]
2020-03-30 Updated OLED module in part library; Scraped current PCB placements
    [pcb.brd, pcb.sch]
2020-03-30 Further updates to OLED module
    [pcb.brd, pcb.sch]
2020-04-03 PCB part placements and partial routing
    [pcb.brd, pcb.sch]
2020-04-03 Finished PCB routing
    [pcb.brd]
2020-04-03 PCB text cleanup
    [pcb.brd]
2020-04-03 Added OLED dimension sketch to schematics
2020-04-04 PLaced images on PCB
    [pcb.brd, pcb.sch]
2020-04-04 Added PCB mounting holes
    [pcb.brd]
2020-04-04 Added BOM files
    [bom-grouped.csv, bom.csv]
2020-04-14 Fixed I2C Pull-ups being Pull-downs
    [pcb.brd, pcb.sch]
2020-04-14 Added Revision 1 indicator to PCB
    [pcb.brd]
2020-05-06 Moved PCB Text away from SMD pads
    [pcb.brd]
2020-05-06 Added PCB (1.0) image to readme
2020-05-15 Added schematics for target board
    [pcb.sch]
2020-05-15 Added target PCB board file
    [pcb.brd, pcb.sch]
2020-05-15 Further work on target board
    [pcb.brd]
2020-05-15 Added transperent StoneLabs logo to schematics media
2020-05-18 Added current chip name/signature to fuse input page
2020-05-18 Added name of currently selected fuse bit to fuse input page
2020-05-19 Added flowchart for UI interaction
2020-05-19 Added UI flowchart to UIM readme
2020-05-19 Added informative text to pins on main pcb
    [pcb.brd]
2020-05-28 Updated part names in target PCB
    [pcb.brd, pcb.sch]
2020-05-28 Added BOM for target PCB
    [bom.csv]

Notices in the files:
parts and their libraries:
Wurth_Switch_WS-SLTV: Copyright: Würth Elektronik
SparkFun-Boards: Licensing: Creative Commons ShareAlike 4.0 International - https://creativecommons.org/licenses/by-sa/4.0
